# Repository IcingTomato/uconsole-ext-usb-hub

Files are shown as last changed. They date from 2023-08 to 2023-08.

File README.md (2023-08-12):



Licence | OSHWA
:-------------------------:|:-------------------------:
 | (https://certification.oshwa.org/de000137.html)

# uConsole USB Hub

This extension board adds 4 additional USB ports to the [uConsole](https://www.clockworkpi.com/uconsole).

## Schematic

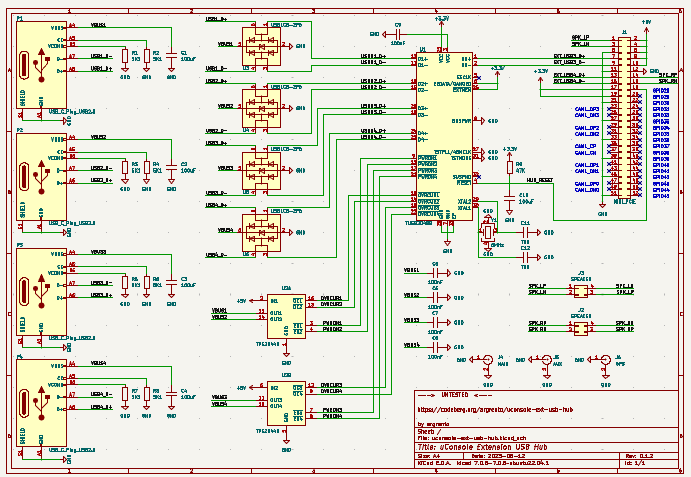
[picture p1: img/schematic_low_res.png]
status-badge (https://codeberg.org/argrento/uconsole-ext-usb-hub/releases)


## PCB

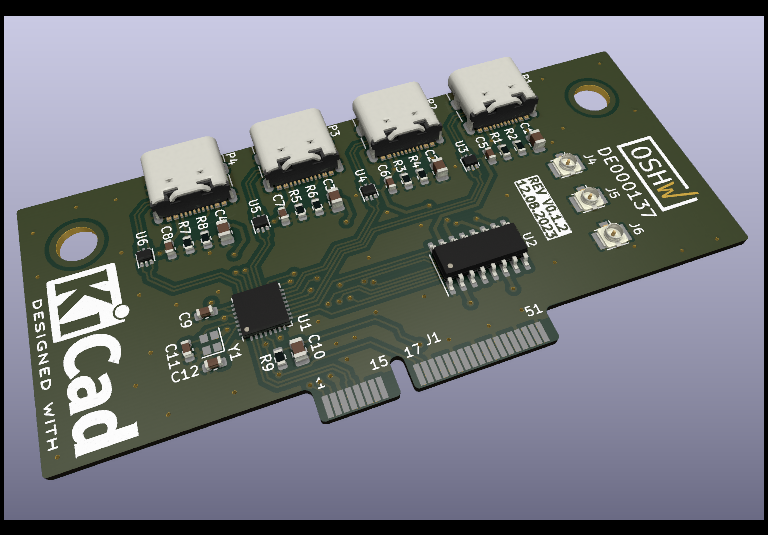
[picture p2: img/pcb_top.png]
pcb-top (https://codeberg.org/argrento/uconsole-ext-usb-hub/releases)

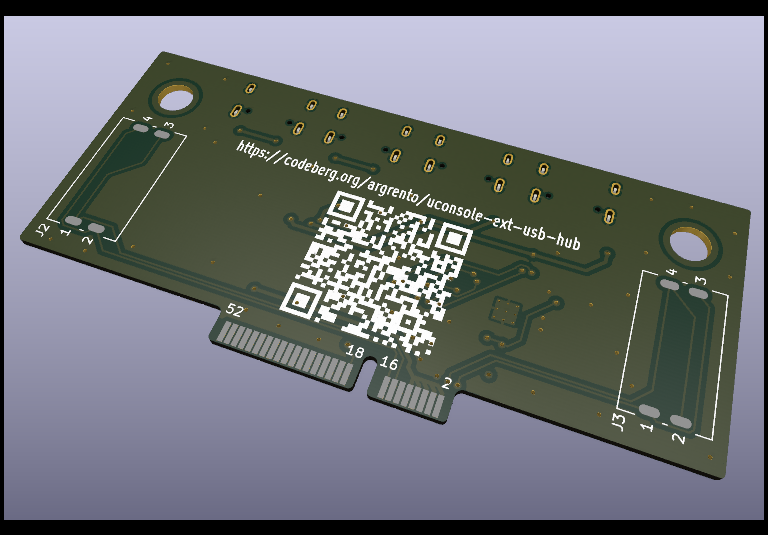
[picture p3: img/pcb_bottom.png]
pcb-bottom (https://codeberg.org/argrento/uconsole-ext-usb-hub/releases)


## Changelog
* 0.1.1
    * Schematic
        * No changes
    * PCB
        * Add OSHW certification
        * Add some info labels and QR code to this repo
* 0.1.0 -- **Production Release**
    * Schematic
        * `HUB_RESET` is now connected to `GPIO28`
        * `U3`, `U4`, `U5`, `U6` are rotated to simplify pcb
    * PCB
        * First PCB version
* 0.0.2
    * Schematic
        * Add speakers
* 0.0.1
    * Initial release

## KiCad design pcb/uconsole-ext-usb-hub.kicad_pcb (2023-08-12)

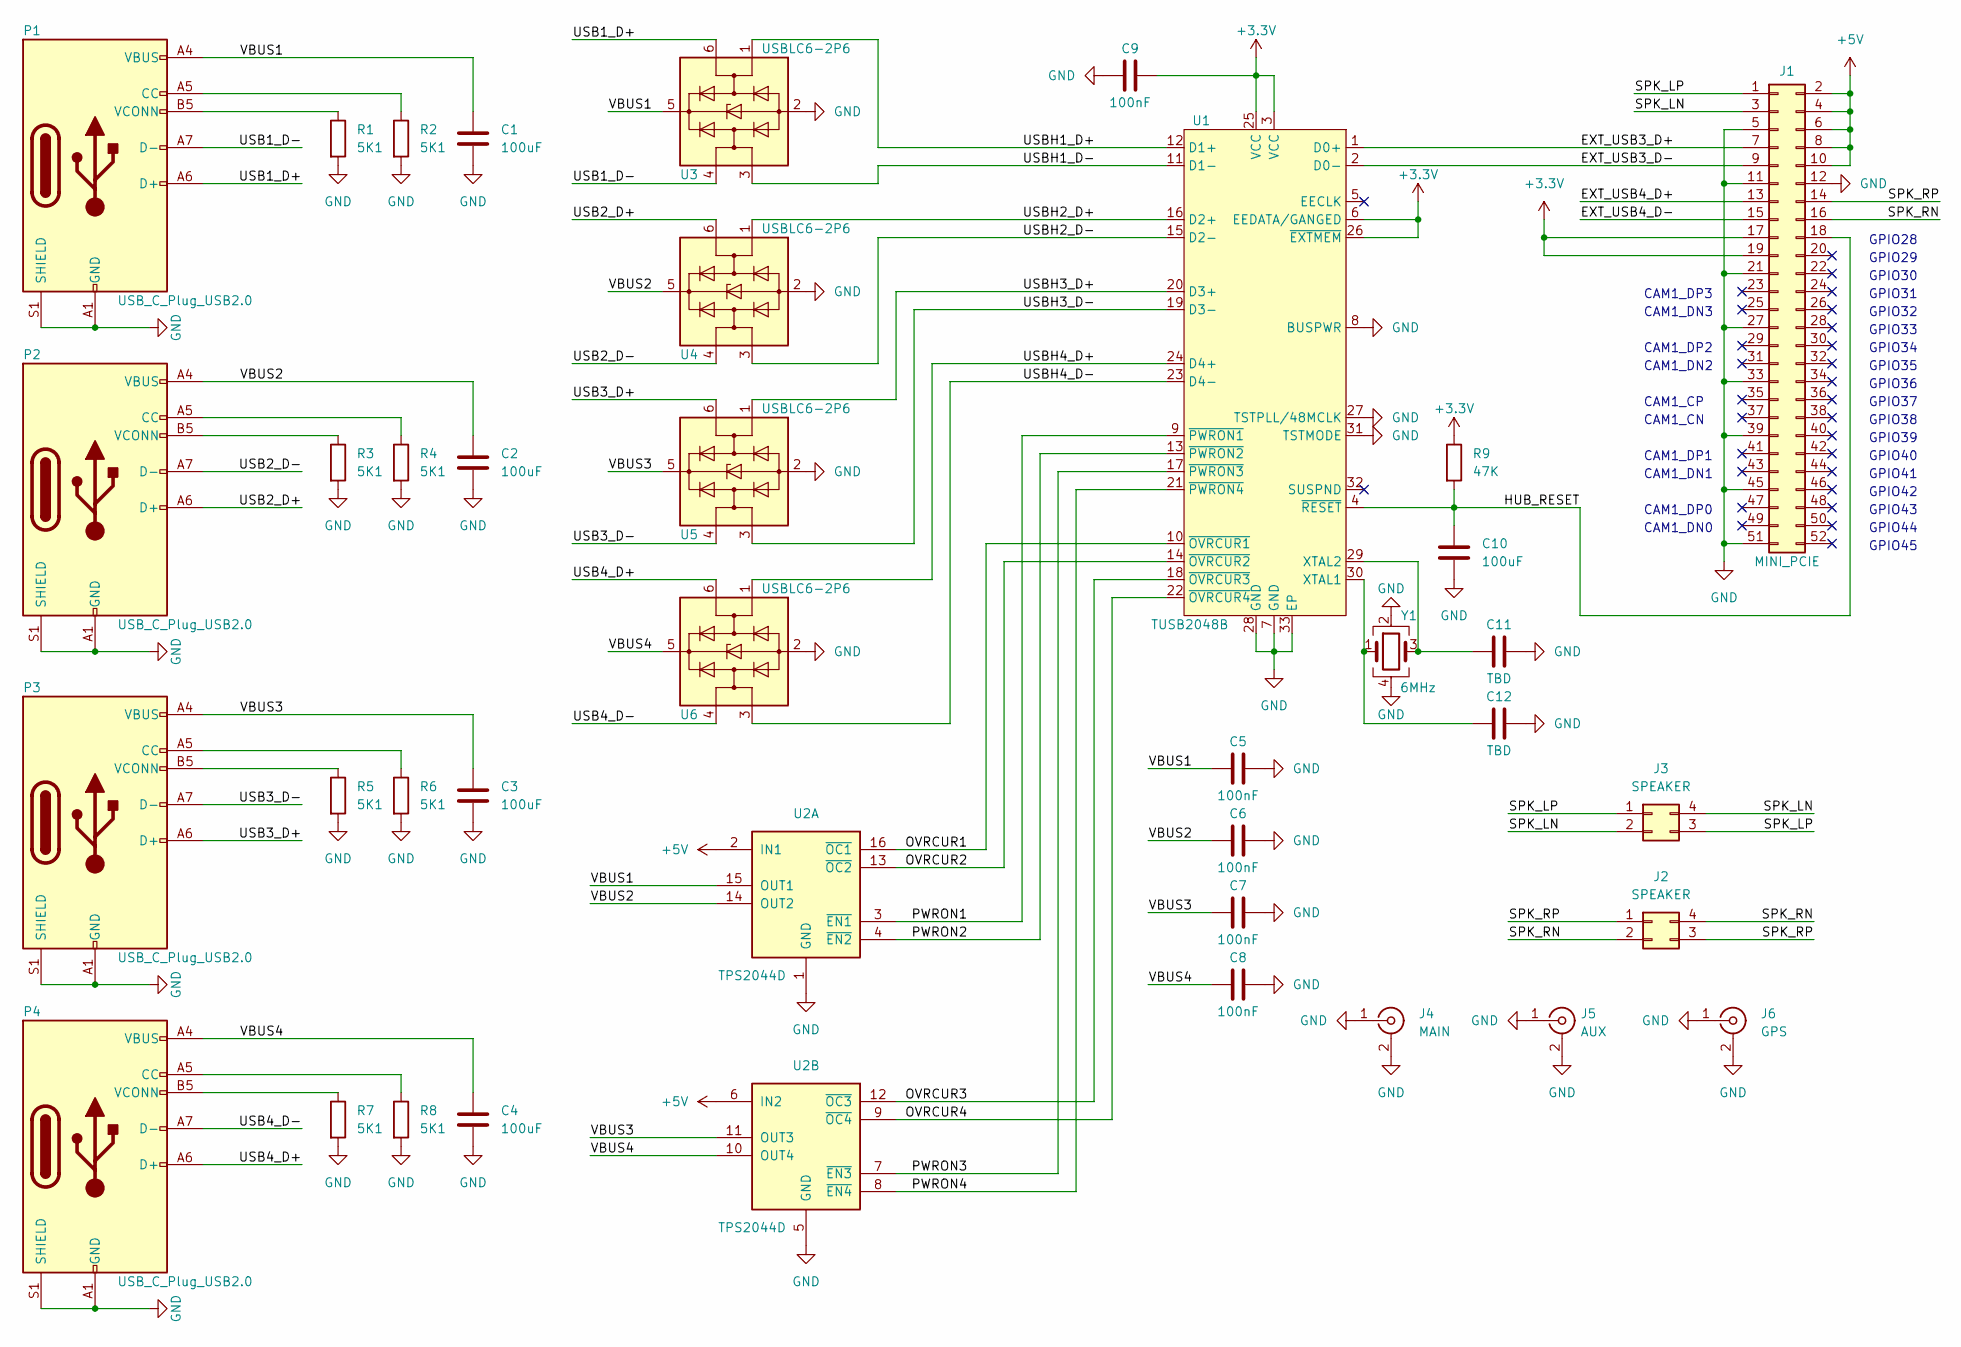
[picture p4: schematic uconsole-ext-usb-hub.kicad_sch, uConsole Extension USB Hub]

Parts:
C1, C2, C3, C4, C10: 100uF; C_0805_2012Metric
C5, C6, C7, C8, C9: 100nF; C_0603_1608Metric
C11, C12: TBD; C_0603_1608Metric
J1: MINI_PCIE; mini_pcie_edge
J2, J3: SPEAKER; uConsole_speaker
J4: MAIN; U.FL_Hirose_U.FL-R-SMT-1_Vertical
J5: AUX; U.FL_Hirose_U.FL-R-SMT-1_Vertical
J6: GPS; U.FL_Hirose_U.FL-R-SMT-1_Vertical
P1, P2, P3, P4: USB_C_Plug_USB2.0; USB_C_Receptacle_GCT_USB4105-xx-A_16P_TopMnt_Horizontal
R1, R2, R3, R4, R5, R6, R7, R8: 5K1; R_0603_1608Metric
R9: 47K; R_0603_1608Metric
U1: TUSB2048B; QFN-32-1EP_5x5mm_P0.5mm_EP3.3x3.3mm_ThermalVias
U2: TPS2044D; SOIC-16_3.9x9.9mm_P1.27mm
U3, U4, U5, U6: USBLC6-2P6; SOT-666
Y1: 6MHz; Crystal_SMD_2016-4Pin_2.0x1.6mm

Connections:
+3.3V: C9.1, J1.17, J1.19, R9.1, U1.3 (VCC), U1.6 (EEDATA/GANGED), U1.25 (VCC), U1.26 (~EXTMEM)
+5V: J1.2, J1.4, J1.6, J1.8, J1.10, U2.2 (IN1), U2.6 (IN2)
/EXT_USB3_D+: J1.7, U1.1 (D0+)
/EXT_USB3_D-: J1.9, U1.2 (D0-)
/EXT_USB4_D+: J1.13
/EXT_USB4_D-: J1.15
/HUB_RESET: C10.1, J1.18, R9.2, U1.4 (~RESET)
/OVRCUR1: U1.10 (~OVRCUR1), U2.16 (~OC1)
/OVRCUR2: U1.14 (~OVRCUR2), U2.13 (~OC2)
/OVRCUR3: U1.18 (~OVRCUR3), U2.12 (~OC3)
/OVRCUR4: U1.22 (~OVRCUR4), U2.9 (~OC4)
/PWRON1: U1.9 (~PWRON1), U2.3 (~EN1)
/PWRON2: U1.13 (~PWRON2), U2.4 (~EN2)
/PWRON3: U1.17 (~PWRON3), U2.7 (~EN3)
/PWRON4: U1.21 (~PWRON4), U2.8 (~EN4)
/SPK_LN: J1.3, J3.2, J3.4
/SPK_LP: J1.1, J3.1, J3.3
/SPK_RN: J1.16, J2.2, J2.4
/SPK_RP: J1.14, J2.1, J2.3
/USB1_D+: P1.A6 (D+), U3.6 (I/O1)
/USB1_D-: P1.A7 (D-), U3.4 (I/O2)
/USB2_D+: P2.A6 (D+), U4.6 (I/O1)
/USB2_D-: P2.A7 (D-), U4.4 (I/O2)
/USB3_D+: P3.A6 (D+), U5.6 (I/O1)
/USB3_D-: P3.A7 (D-), U5.4 (I/O2)
/USB4_D+: P4.A6 (D+), U6.6 (I/O1)
/USB4_D-: P4.A7 (D-), U6.4 (I/O2)
/USBH1_D+: U1.12 (D1+), U3.1 (I/O1)
/USBH1_D-: U1.11 (D1-), U3.3 (I/O2)
/USBH2_D+: U1.16 (D2+), U4.1 (I/O1)
/USBH2_D-: U1.15 (D2-), U4.3 (I/O2)
/USBH3_D+: U1.20 (D3+), U5.1 (I/O1)
/USBH3_D-: U1.19 (D3-), U5.3 (I/O2)
/USBH4_D+: U1.24 (D4+), U6.1 (I/O1)
/USBH4_D-: U1.23 (D4-), U6.3 (I/O2)
/VBUS1: C1.1, C5.1, P1.A4 (VBUS), P1.A9 (VBUS), P1.B4 (VBUS), P1.B9 (VBUS), U2.15 (OUT1), U3.5 (VBUS)
/VBUS2: C2.1, C6.1, P2.A4 (VBUS), P2.A9 (VBUS), P2.B4 (VBUS), P2.B9 (VBUS), U2.14 (OUT2), U4.5 (VBUS)
/VBUS3: C3.1, C7.1, P3.A4 (VBUS), P3.A9 (VBUS), P3.B4 (VBUS), P3.B9 (VBUS), U2.11 (OUT3), U5.5 (VBUS)
/VBUS4: C4.1, C8.1, P4.A4 (VBUS), P4.A9 (VBUS), P4.B4 (VBUS), P4.B9 (VBUS), U2.10 (OUT4), U6.5 (VBUS)
GND: C1.2, C2.2, C3.2, C4.2, C5.2, C6.2, C7.2, C8.2, C9.2, C10.2, C11.2, C12.2, J1.5, J1.11, J1.12, J1.21, J1.27, J1.33, J1.39, J1.45, J1.51, J4.1 (In), J4.2 (Ext), J5.1 (In), J5.2 (Ext), J6.1 (In), J6.2 (Ext), P1.A1 (GND), P1.A12 (GND), P1.B1 (GND), P1.B12 (GND), P1.S1 (SHIELD), P2.A1 (GND), P2.A12 (GND), P2.B1 (GND), P2.B12 (GND), P2.S1 (SHIELD), P3.A1 (GND), P3.A12 (GND), P3.B1 (GND), P3.B12 (GND), P3.S1 (SHIELD), P4.A1 (GND), P4.A12 (GND), P4.B1 (GND), P4.B12 (GND), P4.S1 (SHIELD), R1.2, R2.2, R3.2, R4.2, R5.2, R6.2, R7.2, R8.2, U1.7 (GND), U1.8 (BUSPWR), U1.27 (TSTPLL/48MCLK), U1.28 (GND), U1.31 (TSTMODE), U1.33 (EP), U2.1 (GND), U2.5 (GND), U3.2 (GND), U4.2 (GND), U5.2 (GND), U6.2 (GND), Y1.2, Y1.4
unnamed: P1.A5 (CC), R2.1
unnamed: P1.B5 (VCONN), R1.1
unnamed: P2.A5 (CC), R4.1
unnamed: P2.B5 (VCONN), R3.1
unnamed: P3.A5 (CC), R6.1
unnamed: P3.B5 (VCONN), R5.1
unnamed: P4.A5 (CC), R8.1
unnamed: P4.B5 (VCONN), R7.1
unnamed: C12.1, U1.30 (XTAL1), Y1.1
unnamed: C11.1, U1.29 (XTAL2), Y1.3

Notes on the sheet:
CAM1_DN1
GPIO43
CAM1_DP3
CAM1_DP0
GPIO31
GPIO42
CAM1_DN3
GPIO29
CAM1_DP2
GPIO41
CAM1_DP1
GPIO32
GPIO28
GPIO38
GPIO30
CAM1_DN2
CAM1_DN0
GPIO39
CAM1_CP
GPIO34
GPIO37
GPIO33
CAM1_CN
GPIO36
GPIO35
GPIO44
GPIO45
GPIO40

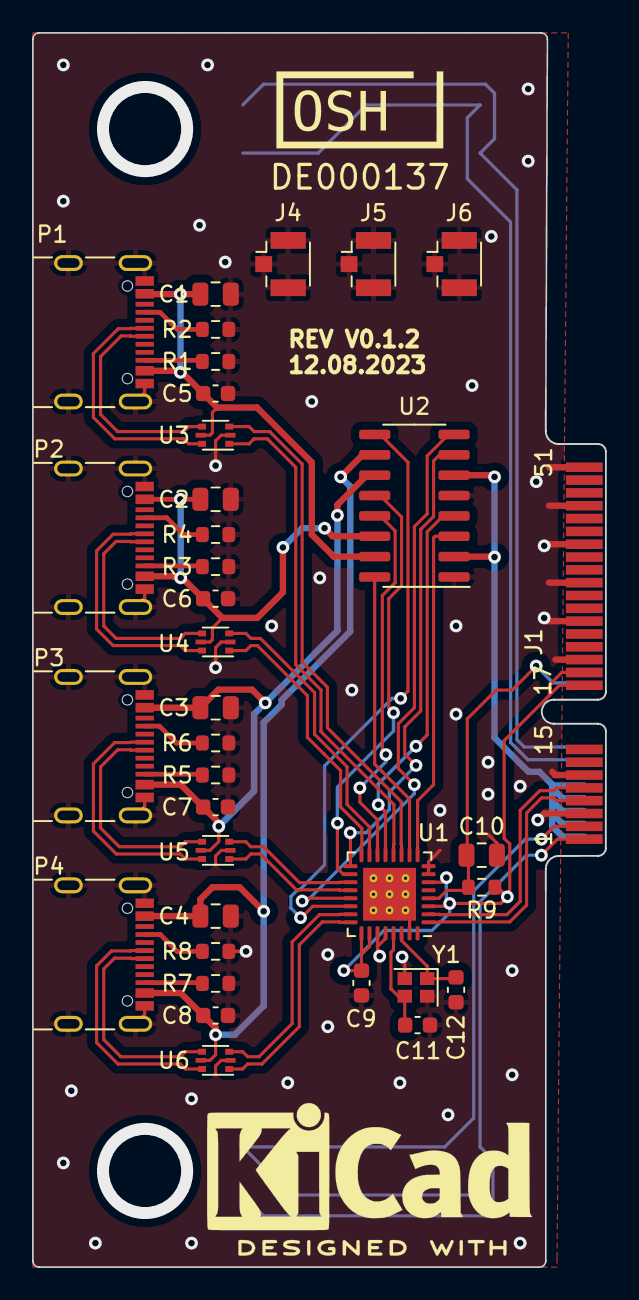
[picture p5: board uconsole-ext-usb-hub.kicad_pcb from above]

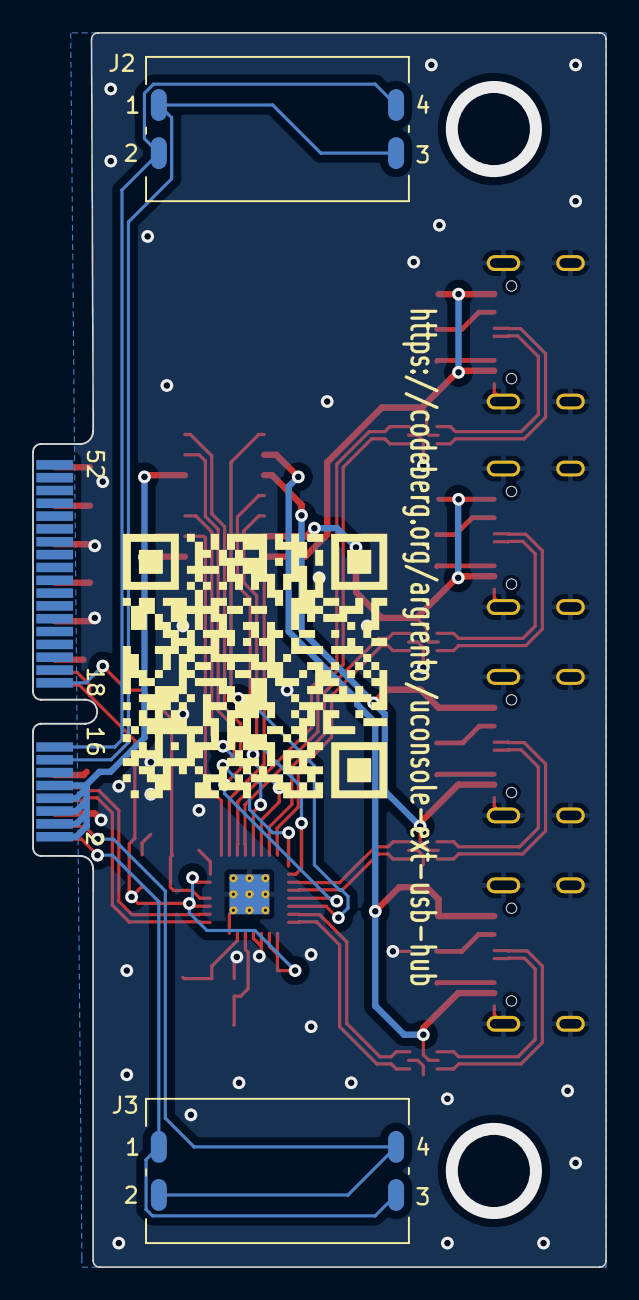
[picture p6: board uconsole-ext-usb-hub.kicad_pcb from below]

Board: 2 copper layers, 35.8 x 77.0 mm, 40 parts (3 on the bottom side), 48 nets.

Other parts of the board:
OSHW_Dual_0.25_Scale: DE000137; OSHW_Dual_0.25_Scale
QR: qr-https--codeberg.org-argrento-uconsole-ext-usb-hub

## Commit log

2023-08-12 Some updates of sch, pcb and readme
    * Add 3 u.fl connectors for antennas
    * Update pictures in readme
    [uconsole-ext-usb-hub.kicad_pcb, uconsole-ext-usb-hub.kicad_sch]
2023-08-13 ci: externalize project name
    * Project name is now in env variable for convenience
    * Number of layers is in in env vars
    * Inner layers are created if there are 4 layers only
    * Add csv BOM generation (Close #2)
    * Add InteractiveHtmlBom
    * Add OSHW logo (Close #3)
